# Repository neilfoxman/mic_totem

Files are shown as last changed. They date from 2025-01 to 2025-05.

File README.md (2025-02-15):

# File Structure Tour

TBD

# Firmware

## State Machine

The program is responsible for both filtering microphone samples and updating LEDs based on the filtered signals. This behavior is achieved by cycling through a loop in a state machine shown below.

```mermaid
---
title: State Machine in main.c
---
stateDiagram-v2

classDef state_style text-align:left

config_mic_s : config_mic_s
config_mic_s:::state_style
[*] --> config_mic_s
config_mic_s : <b>ENTER/</b>
config_mic_s : - Disable timer, DMA, and LED Output
config_mic_s : - Update timer period
config_mic_s : - Calculate filter params
config_mic_s : - Enable DMA, ADC, and Timer

config_mic_s --> mic_s : TIM_UE
mic_s:::state_style
mic_s : mic_s
mic_s : <b>ENTER/</b>
mic_s : <b>MIC_DMA_COMPLETE/</b>
mic_s : - Called after all ADC channels sampled once.
mic_s : - Apply filters to mic signal.

mic_s --> config_led_s : num_samples_taken >= num_samples_before_LED
config_led_s : config_led_s
config_led_s:::state_style
config_led_s : <b>ENTER/</b>
config_led_s : - Disable timer, ADC, and DMA
config_led_s : - Calculate new LED Values and generate CCR values in array
config_led_s : - Update timer period
config_led_s : - Enable DMA and timer.

config_led_s --> led_s : TIM_UE
led_s : led_s
led_s:::state_style
led_s : <b>ENTER/</b>

led_s --> config_mic_s : LED_DMA_COMPLETE

```

The loops takes advantage of persistence of vision i.e. we can take a number of microphone samples then pause periodically to update LED values.  Note that the timer is used both for triggering samples of the microphone, then repurposed in output compare mode to communicate with the LEDs.

## Microphone Filtering

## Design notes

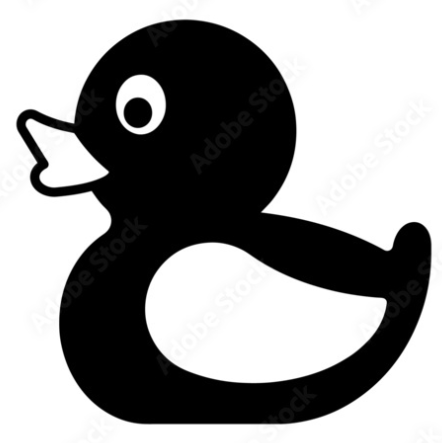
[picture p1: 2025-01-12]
Duckie.png

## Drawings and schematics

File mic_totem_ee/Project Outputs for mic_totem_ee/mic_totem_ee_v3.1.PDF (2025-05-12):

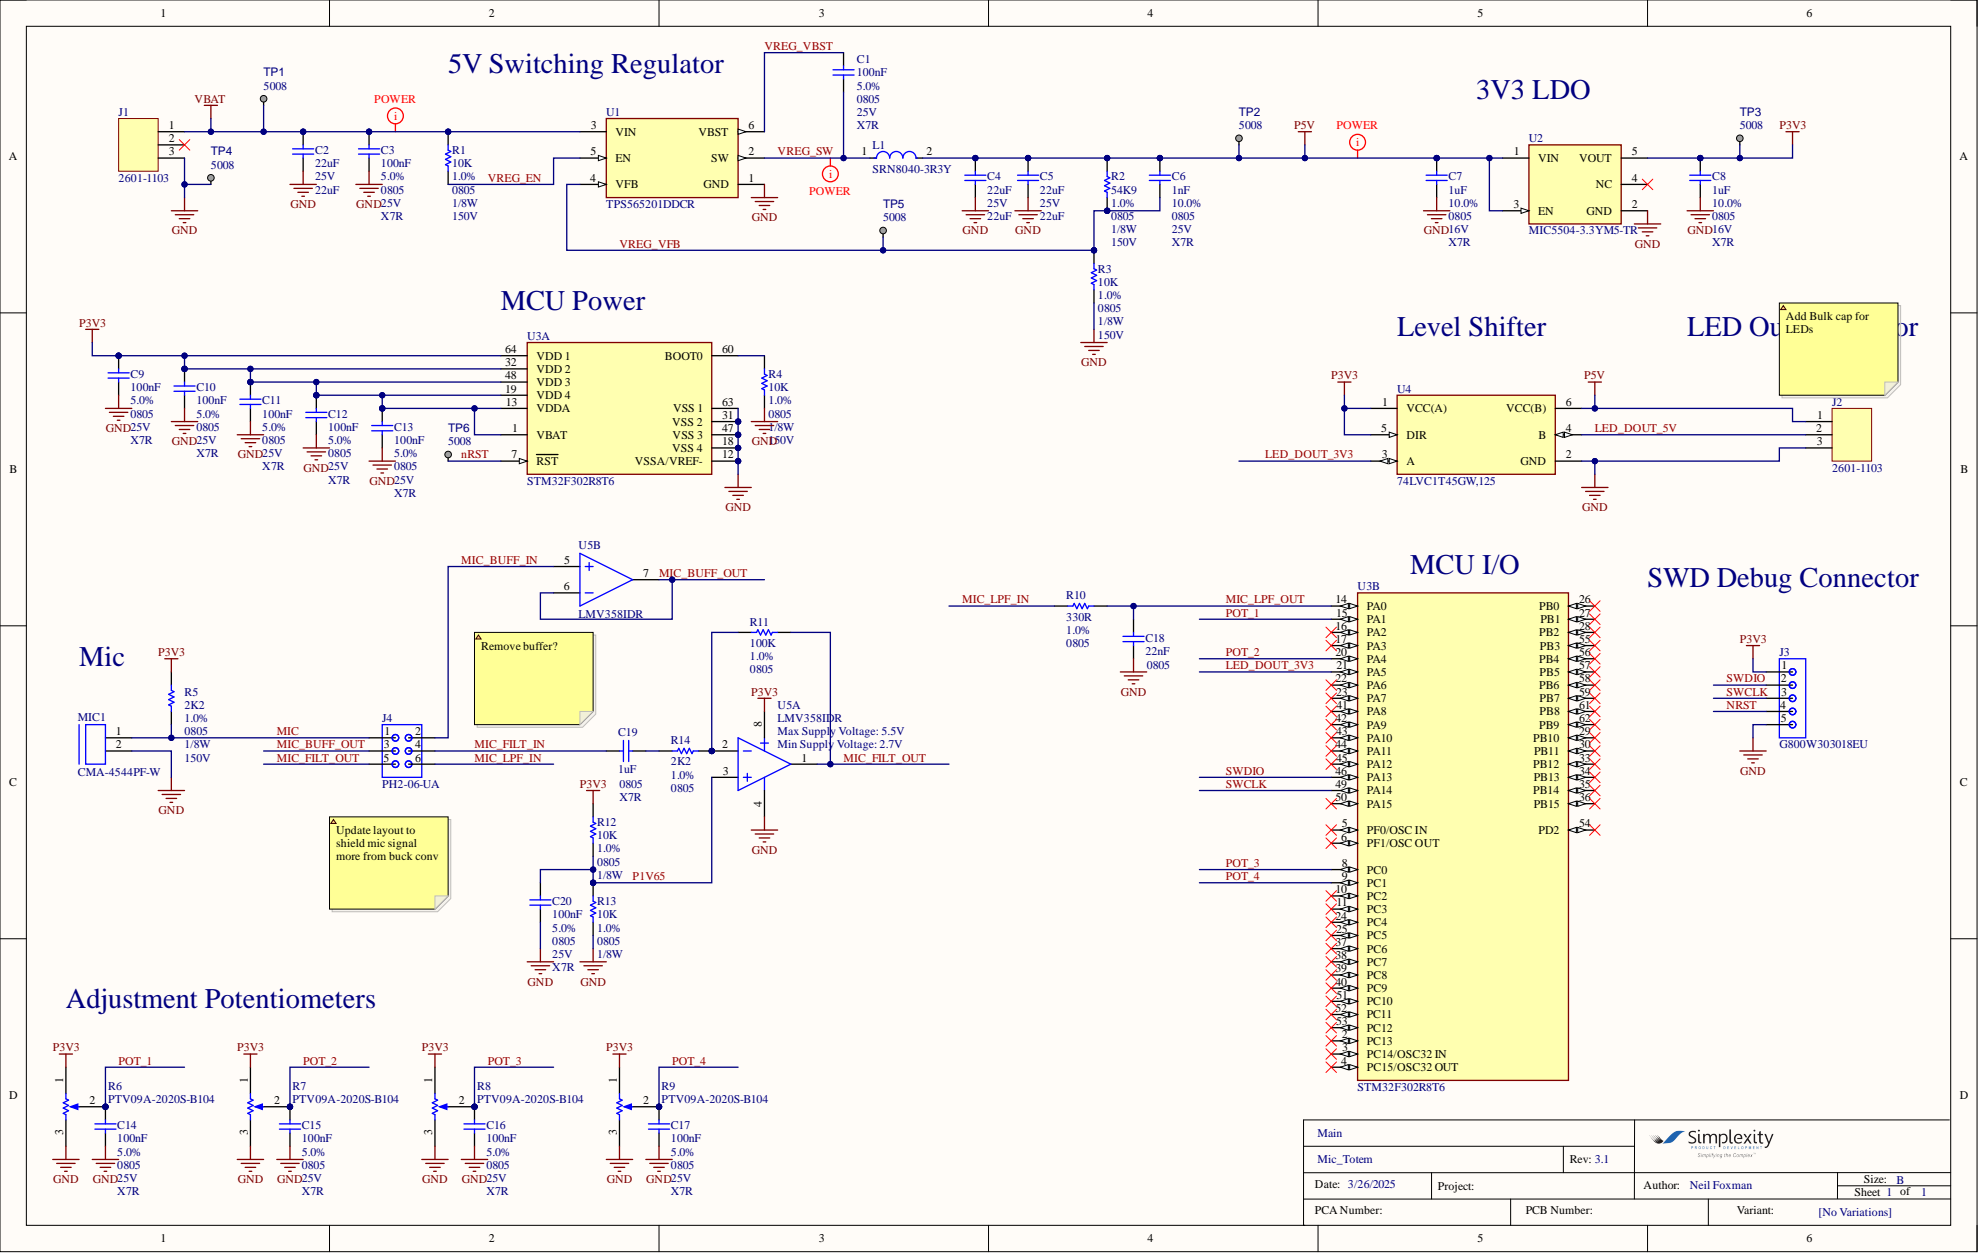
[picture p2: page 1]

Add Bulk cap for
LEDs

VDD 2 32
VDD 3 48
VDD 4 19

Update layout to
shield mic signal
more from buck conv

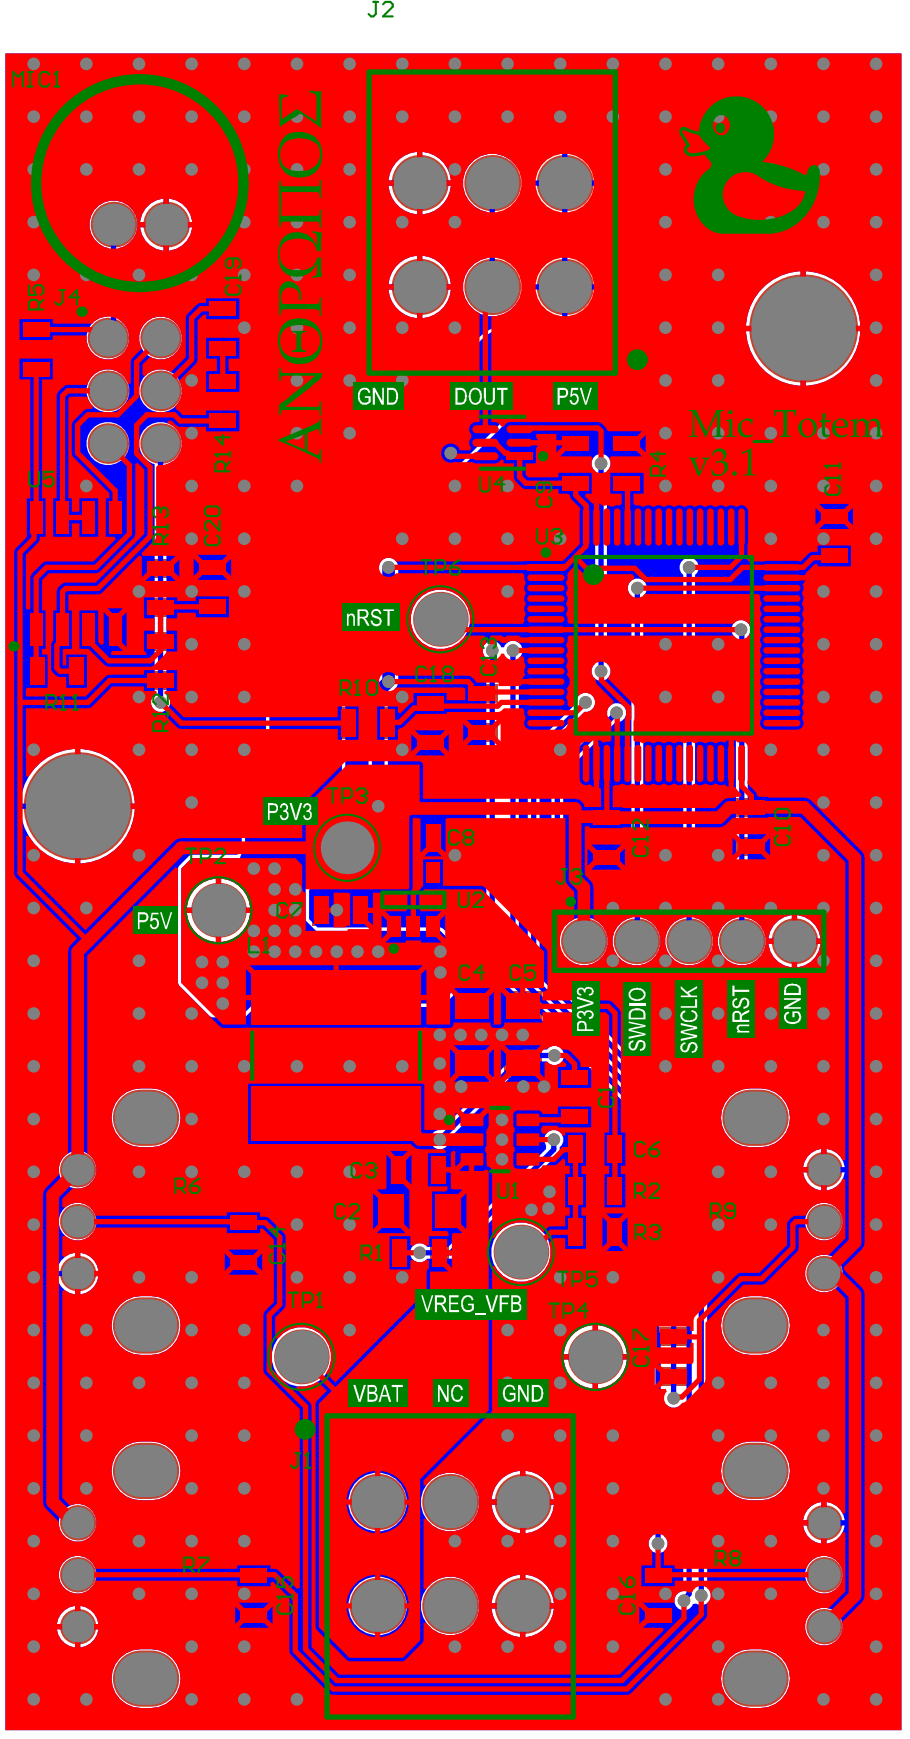
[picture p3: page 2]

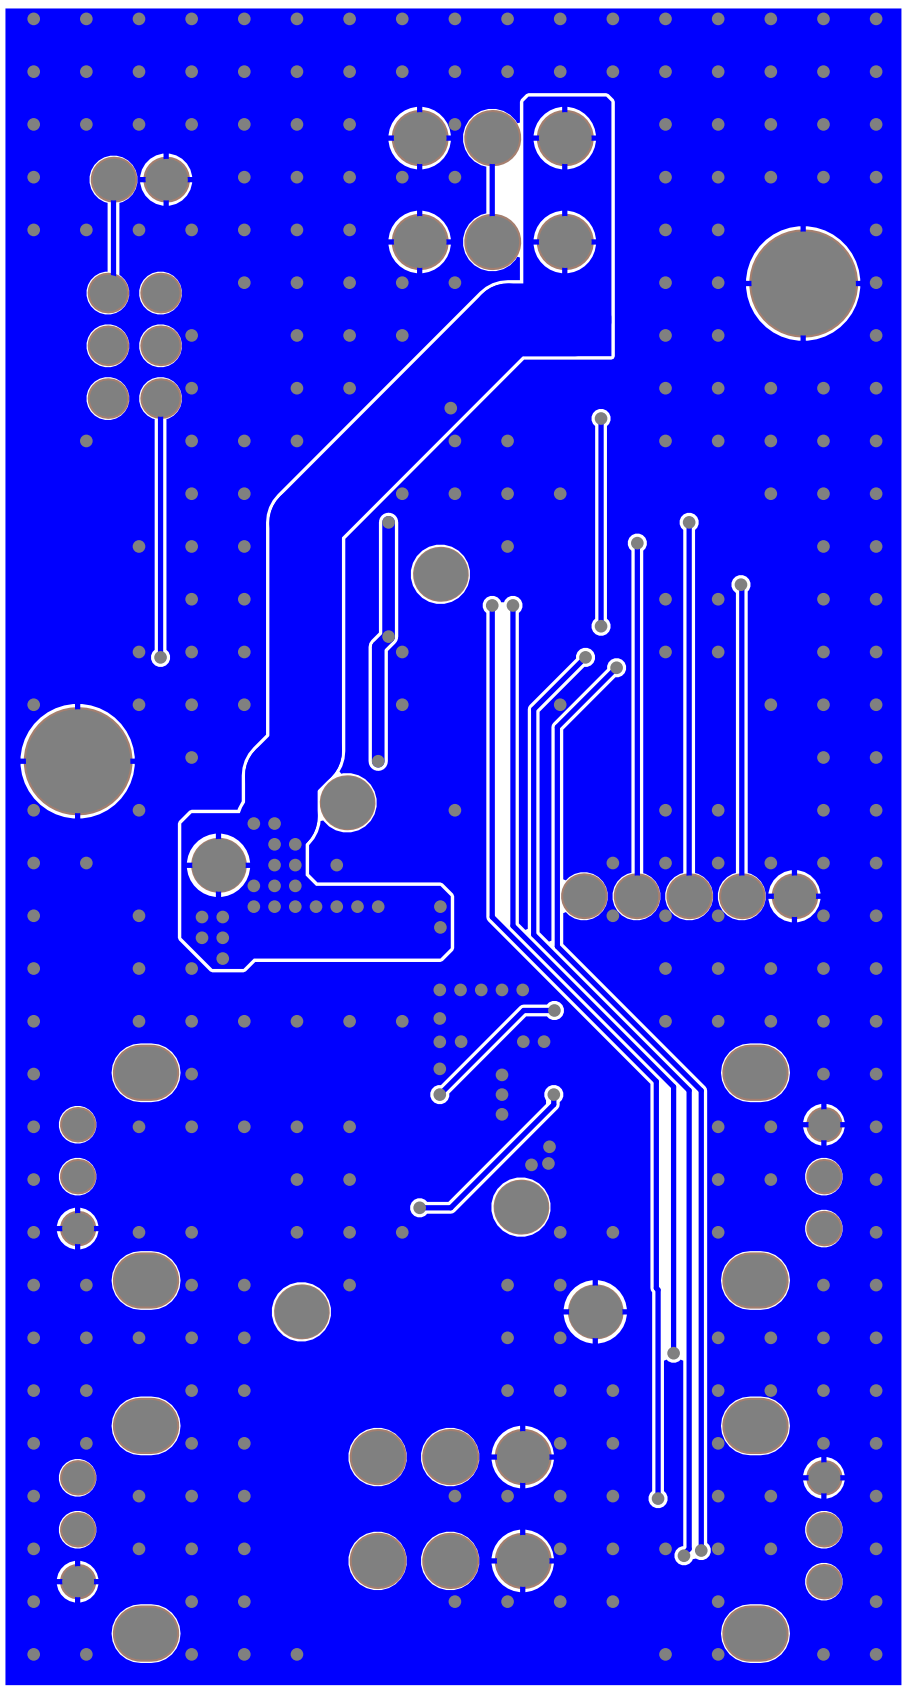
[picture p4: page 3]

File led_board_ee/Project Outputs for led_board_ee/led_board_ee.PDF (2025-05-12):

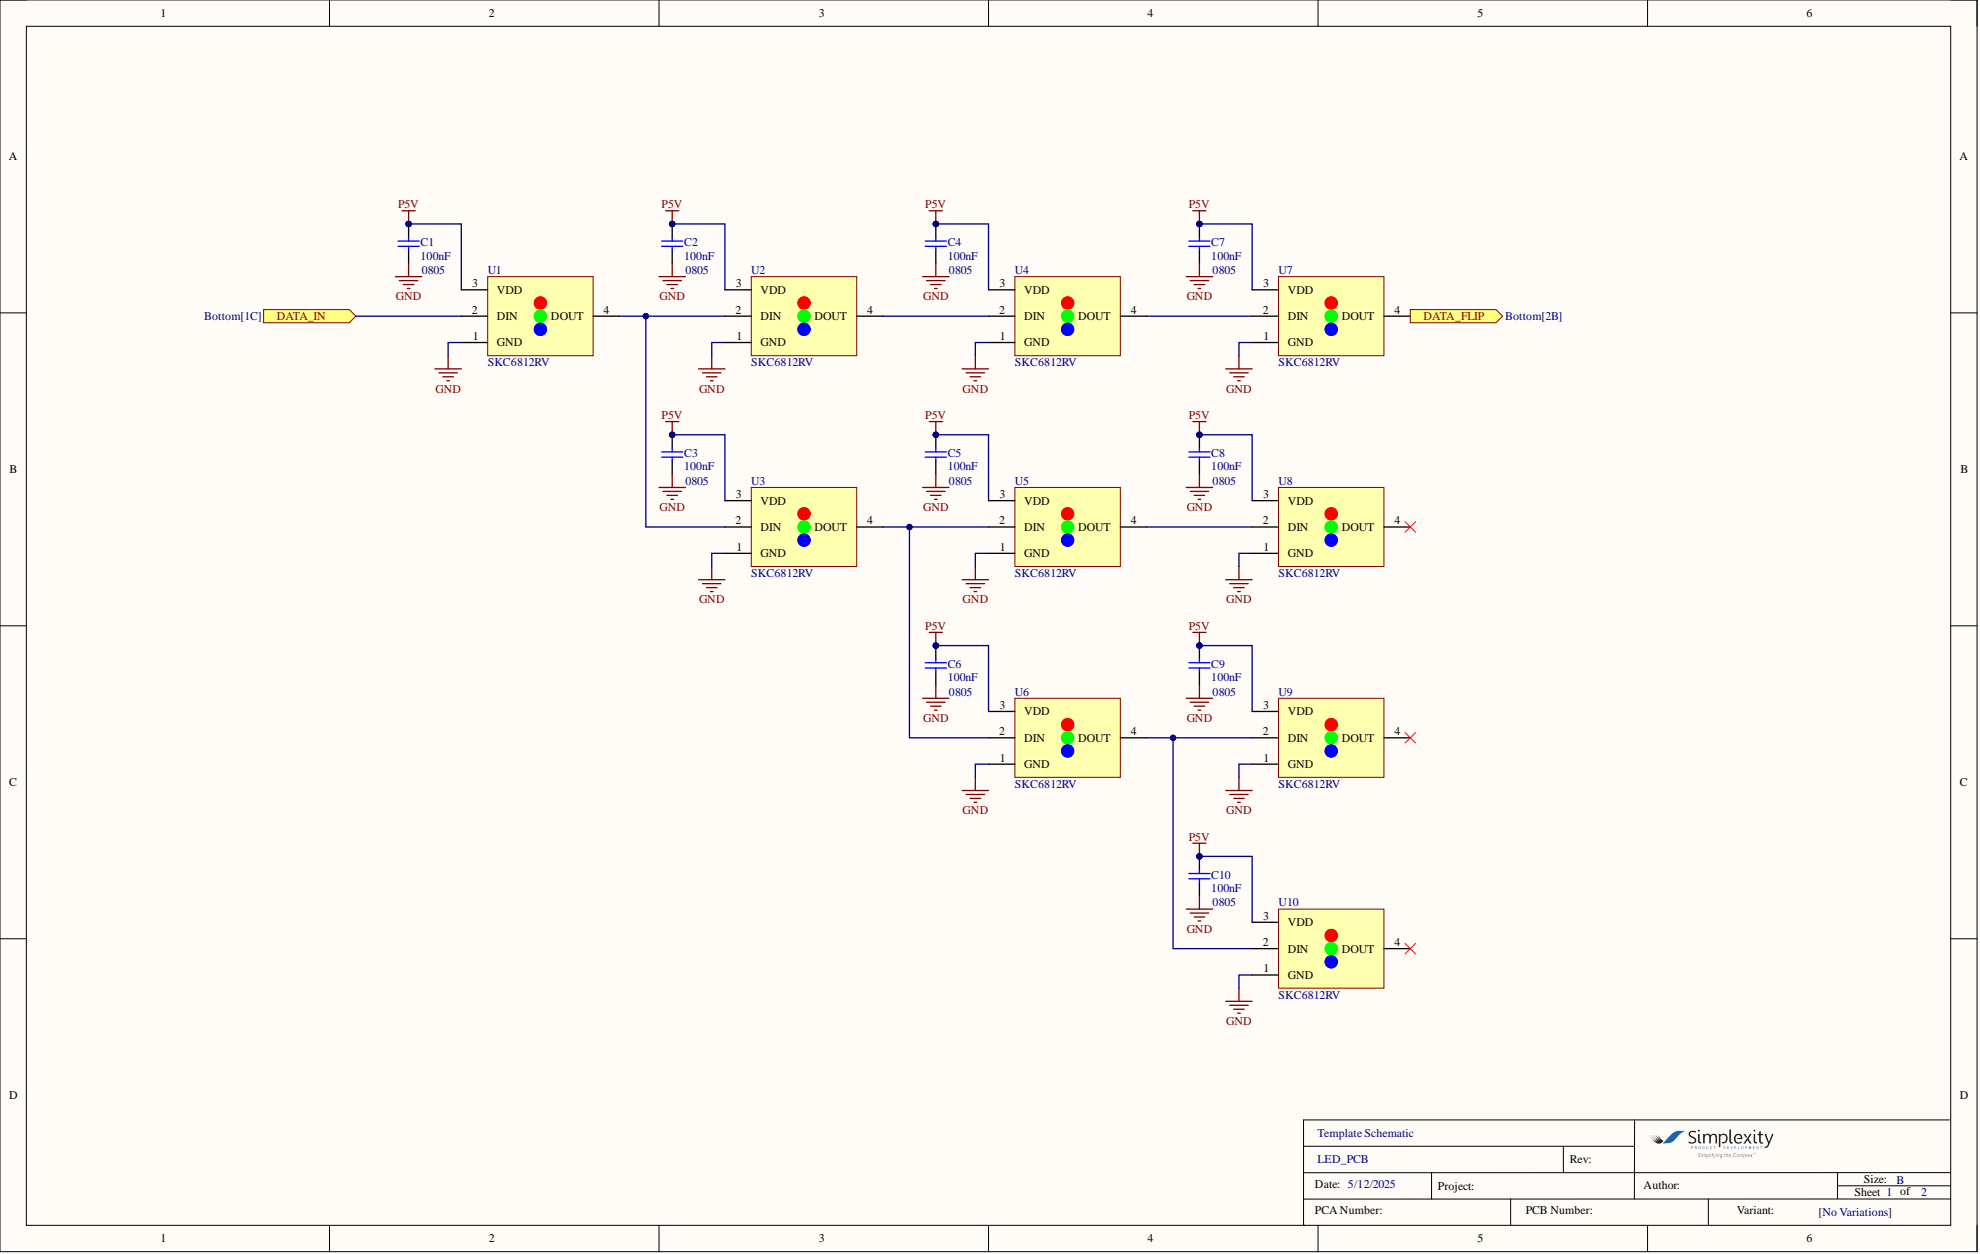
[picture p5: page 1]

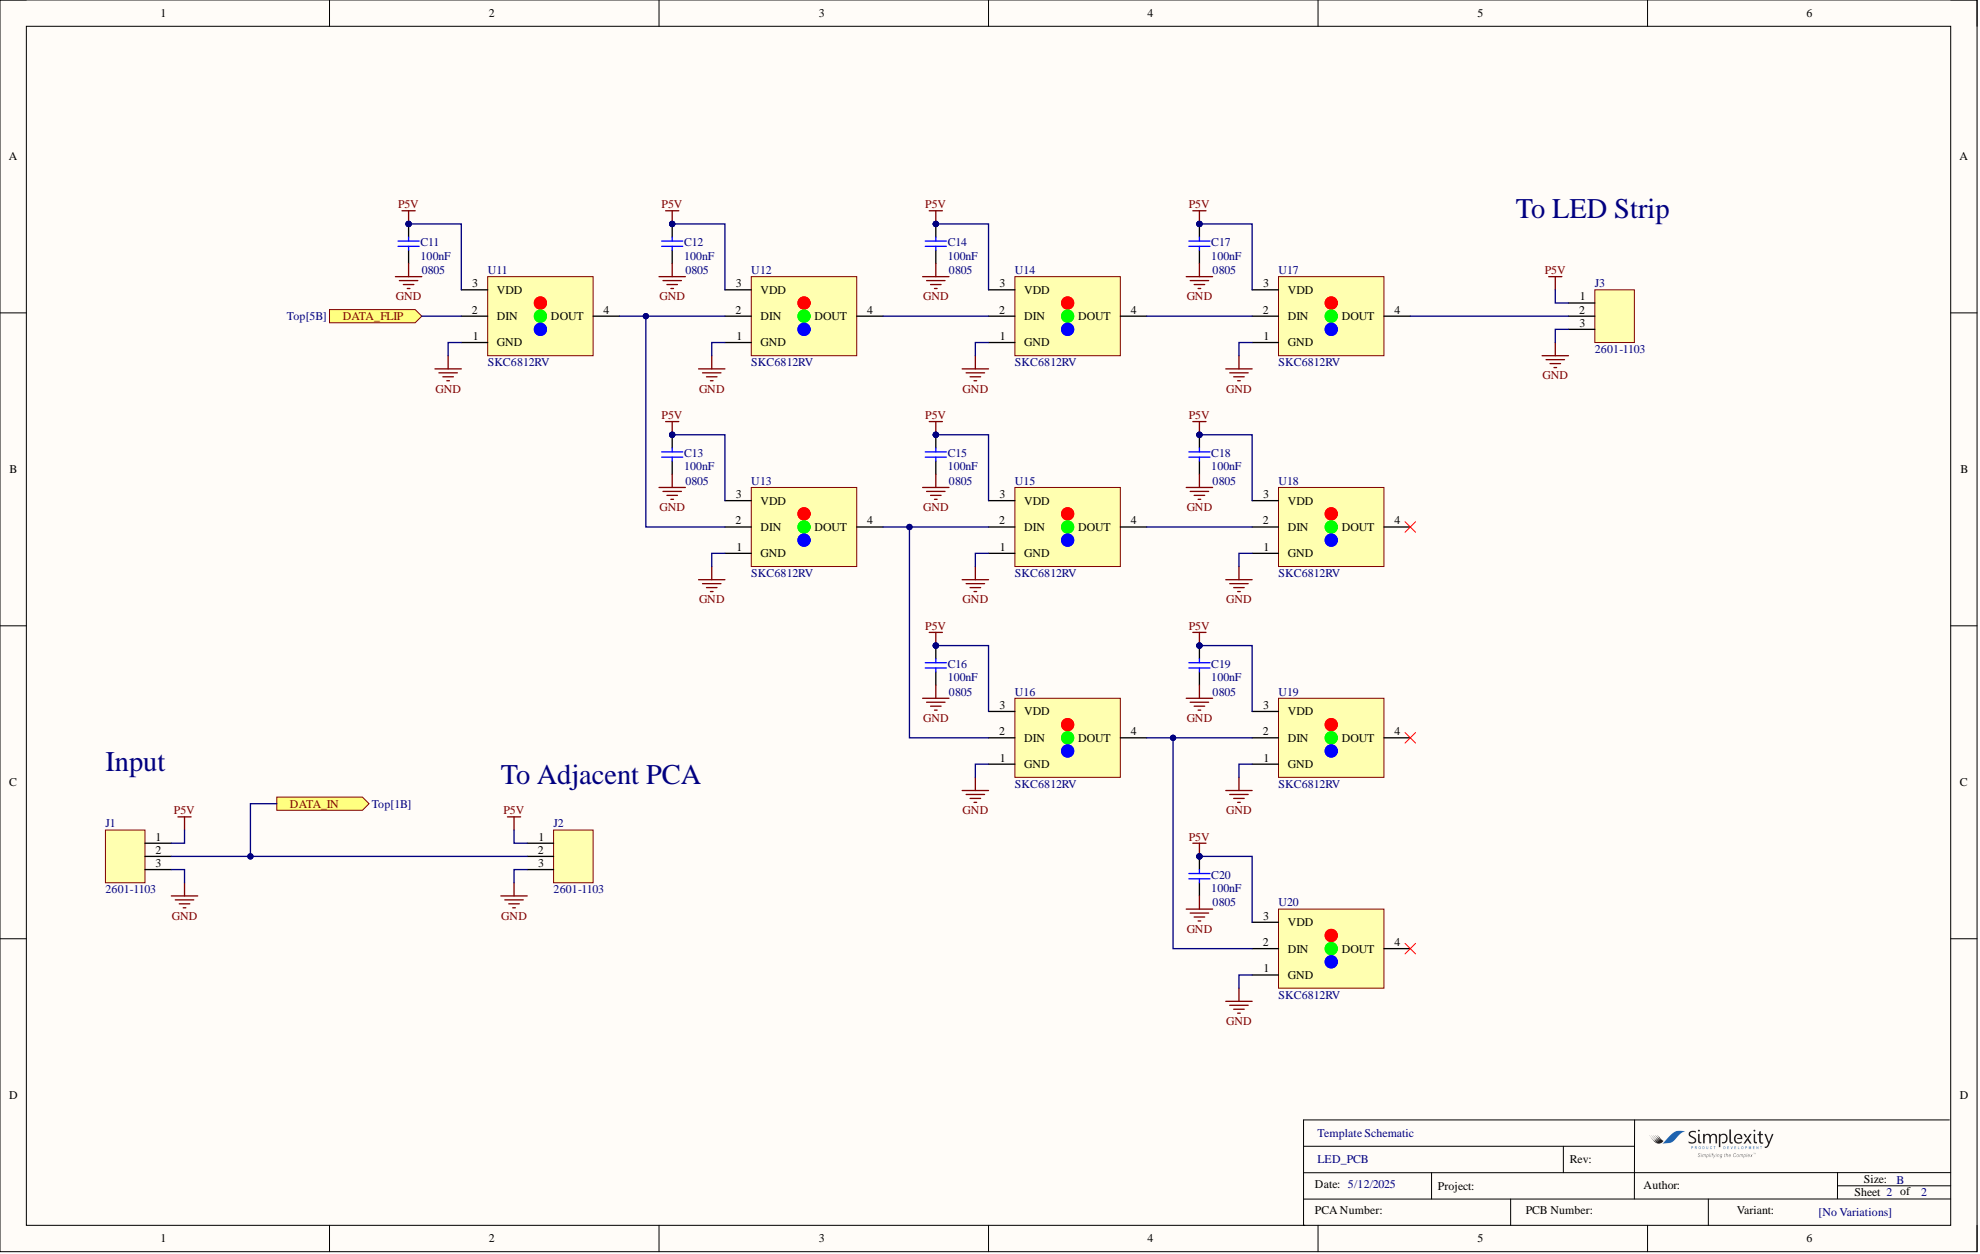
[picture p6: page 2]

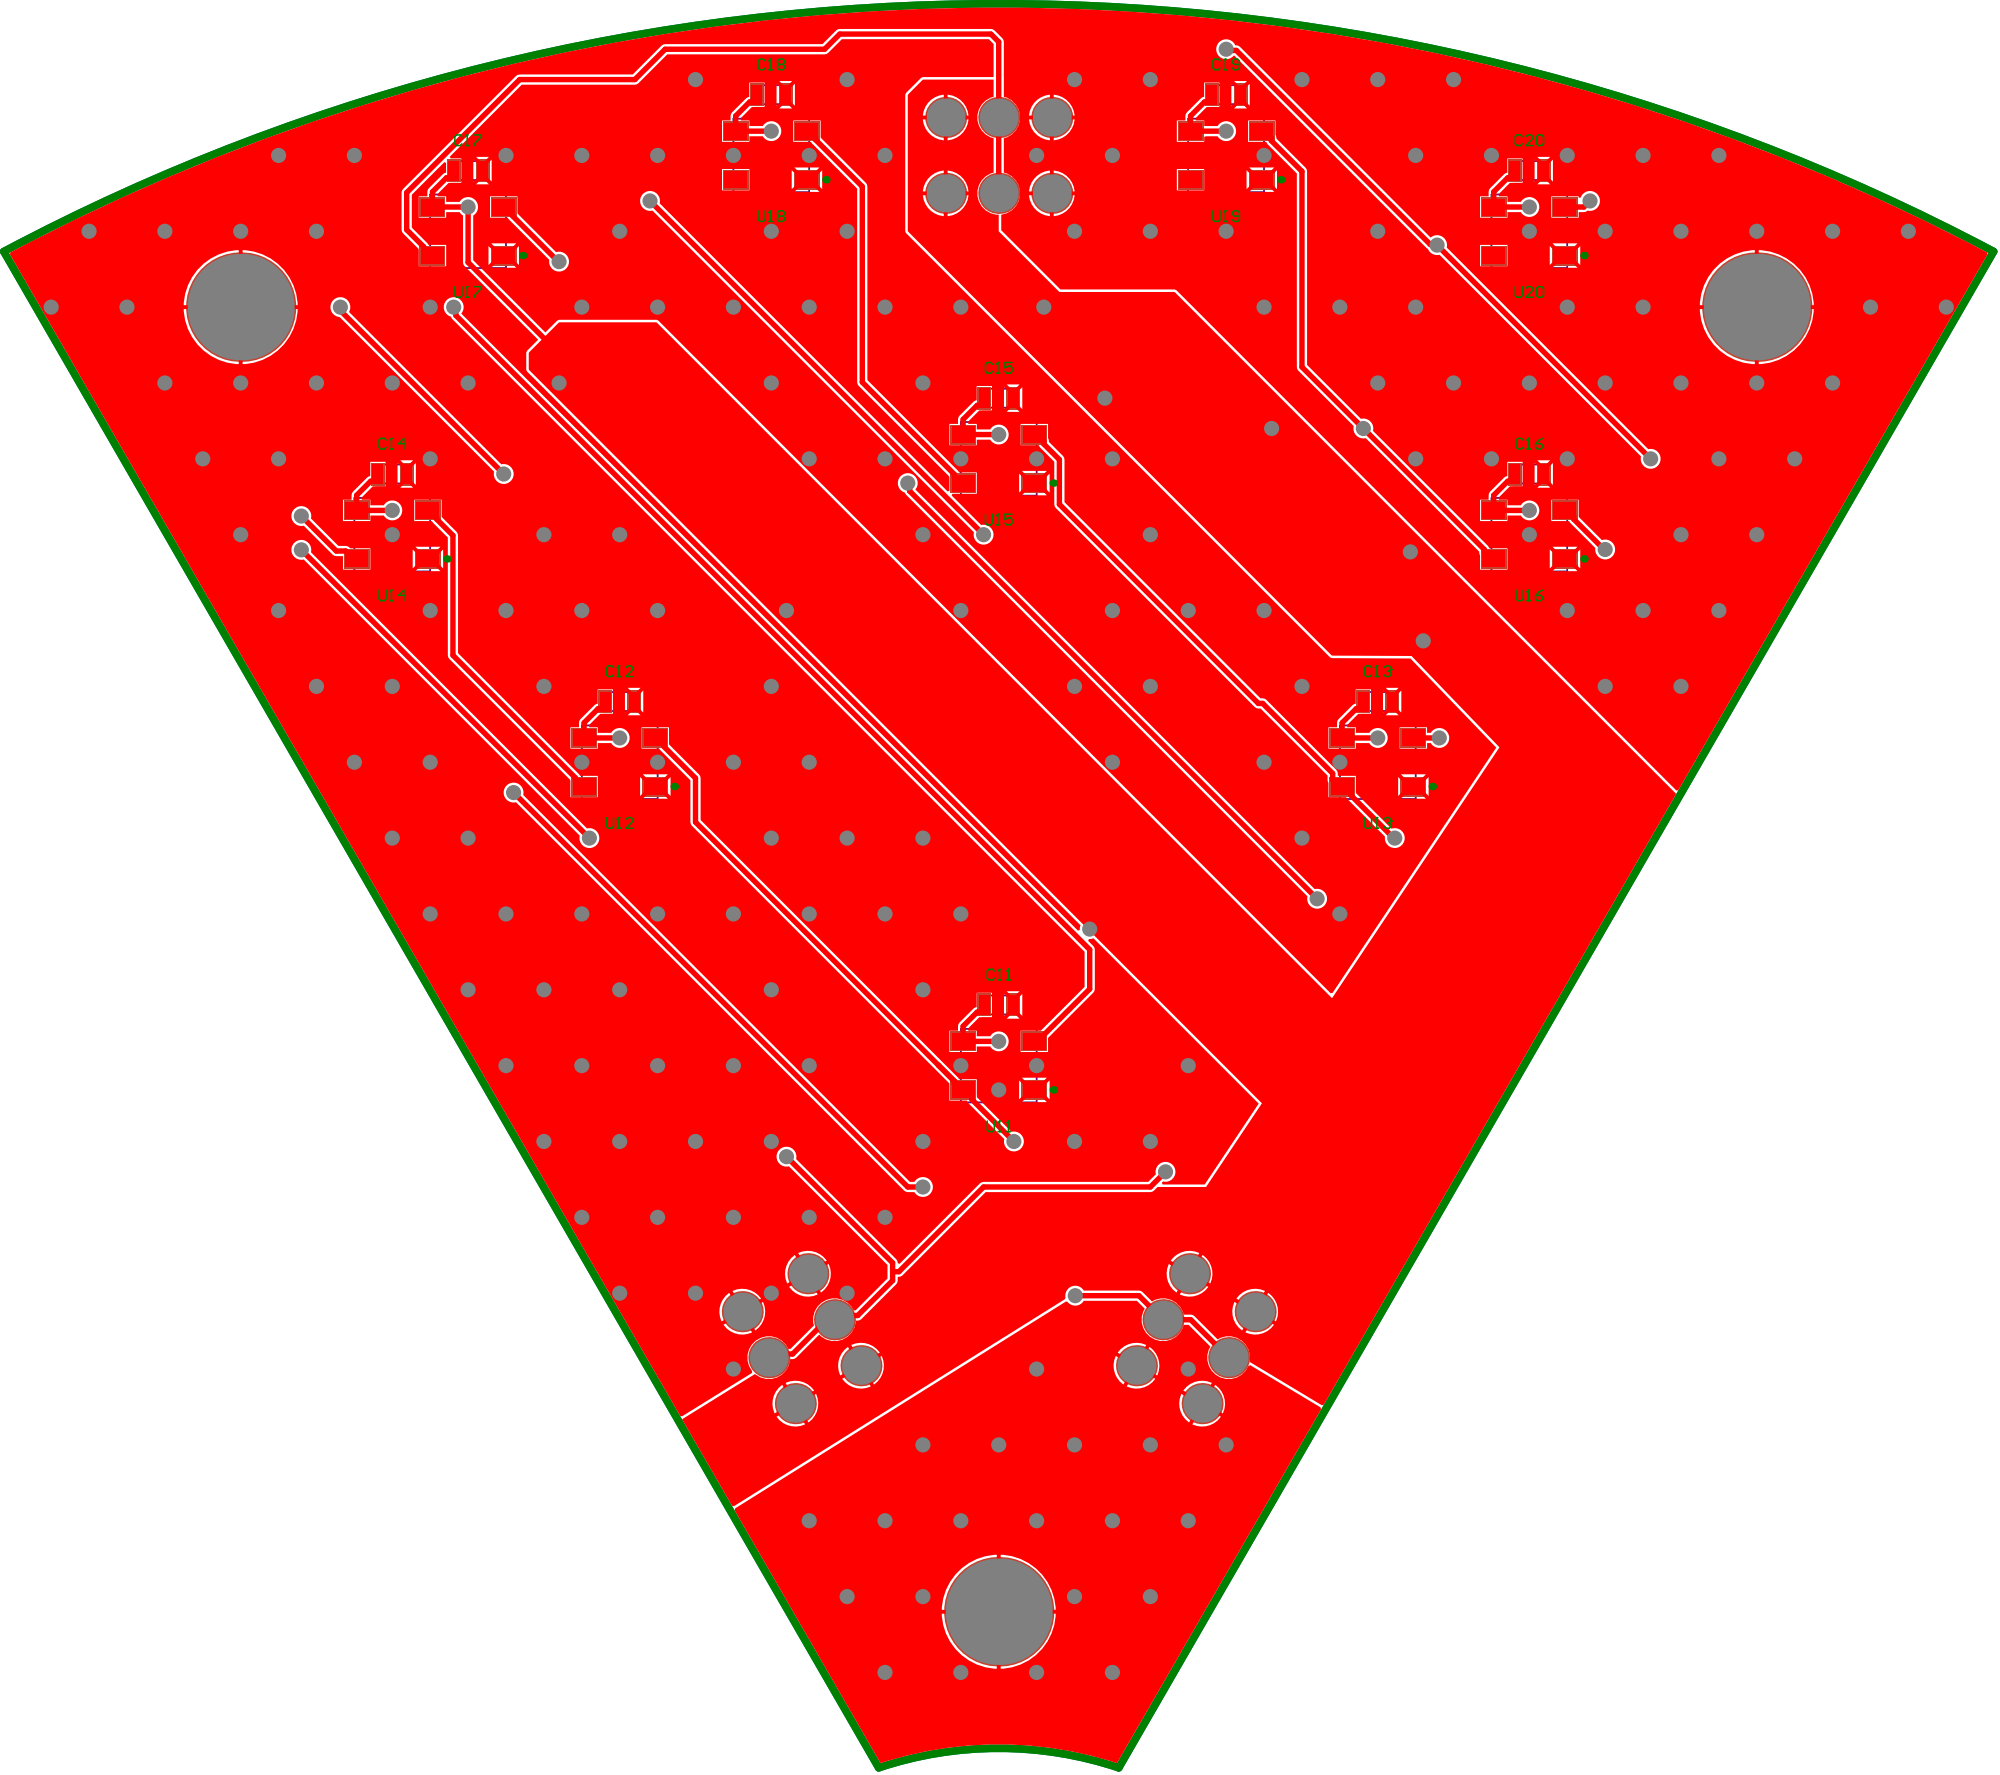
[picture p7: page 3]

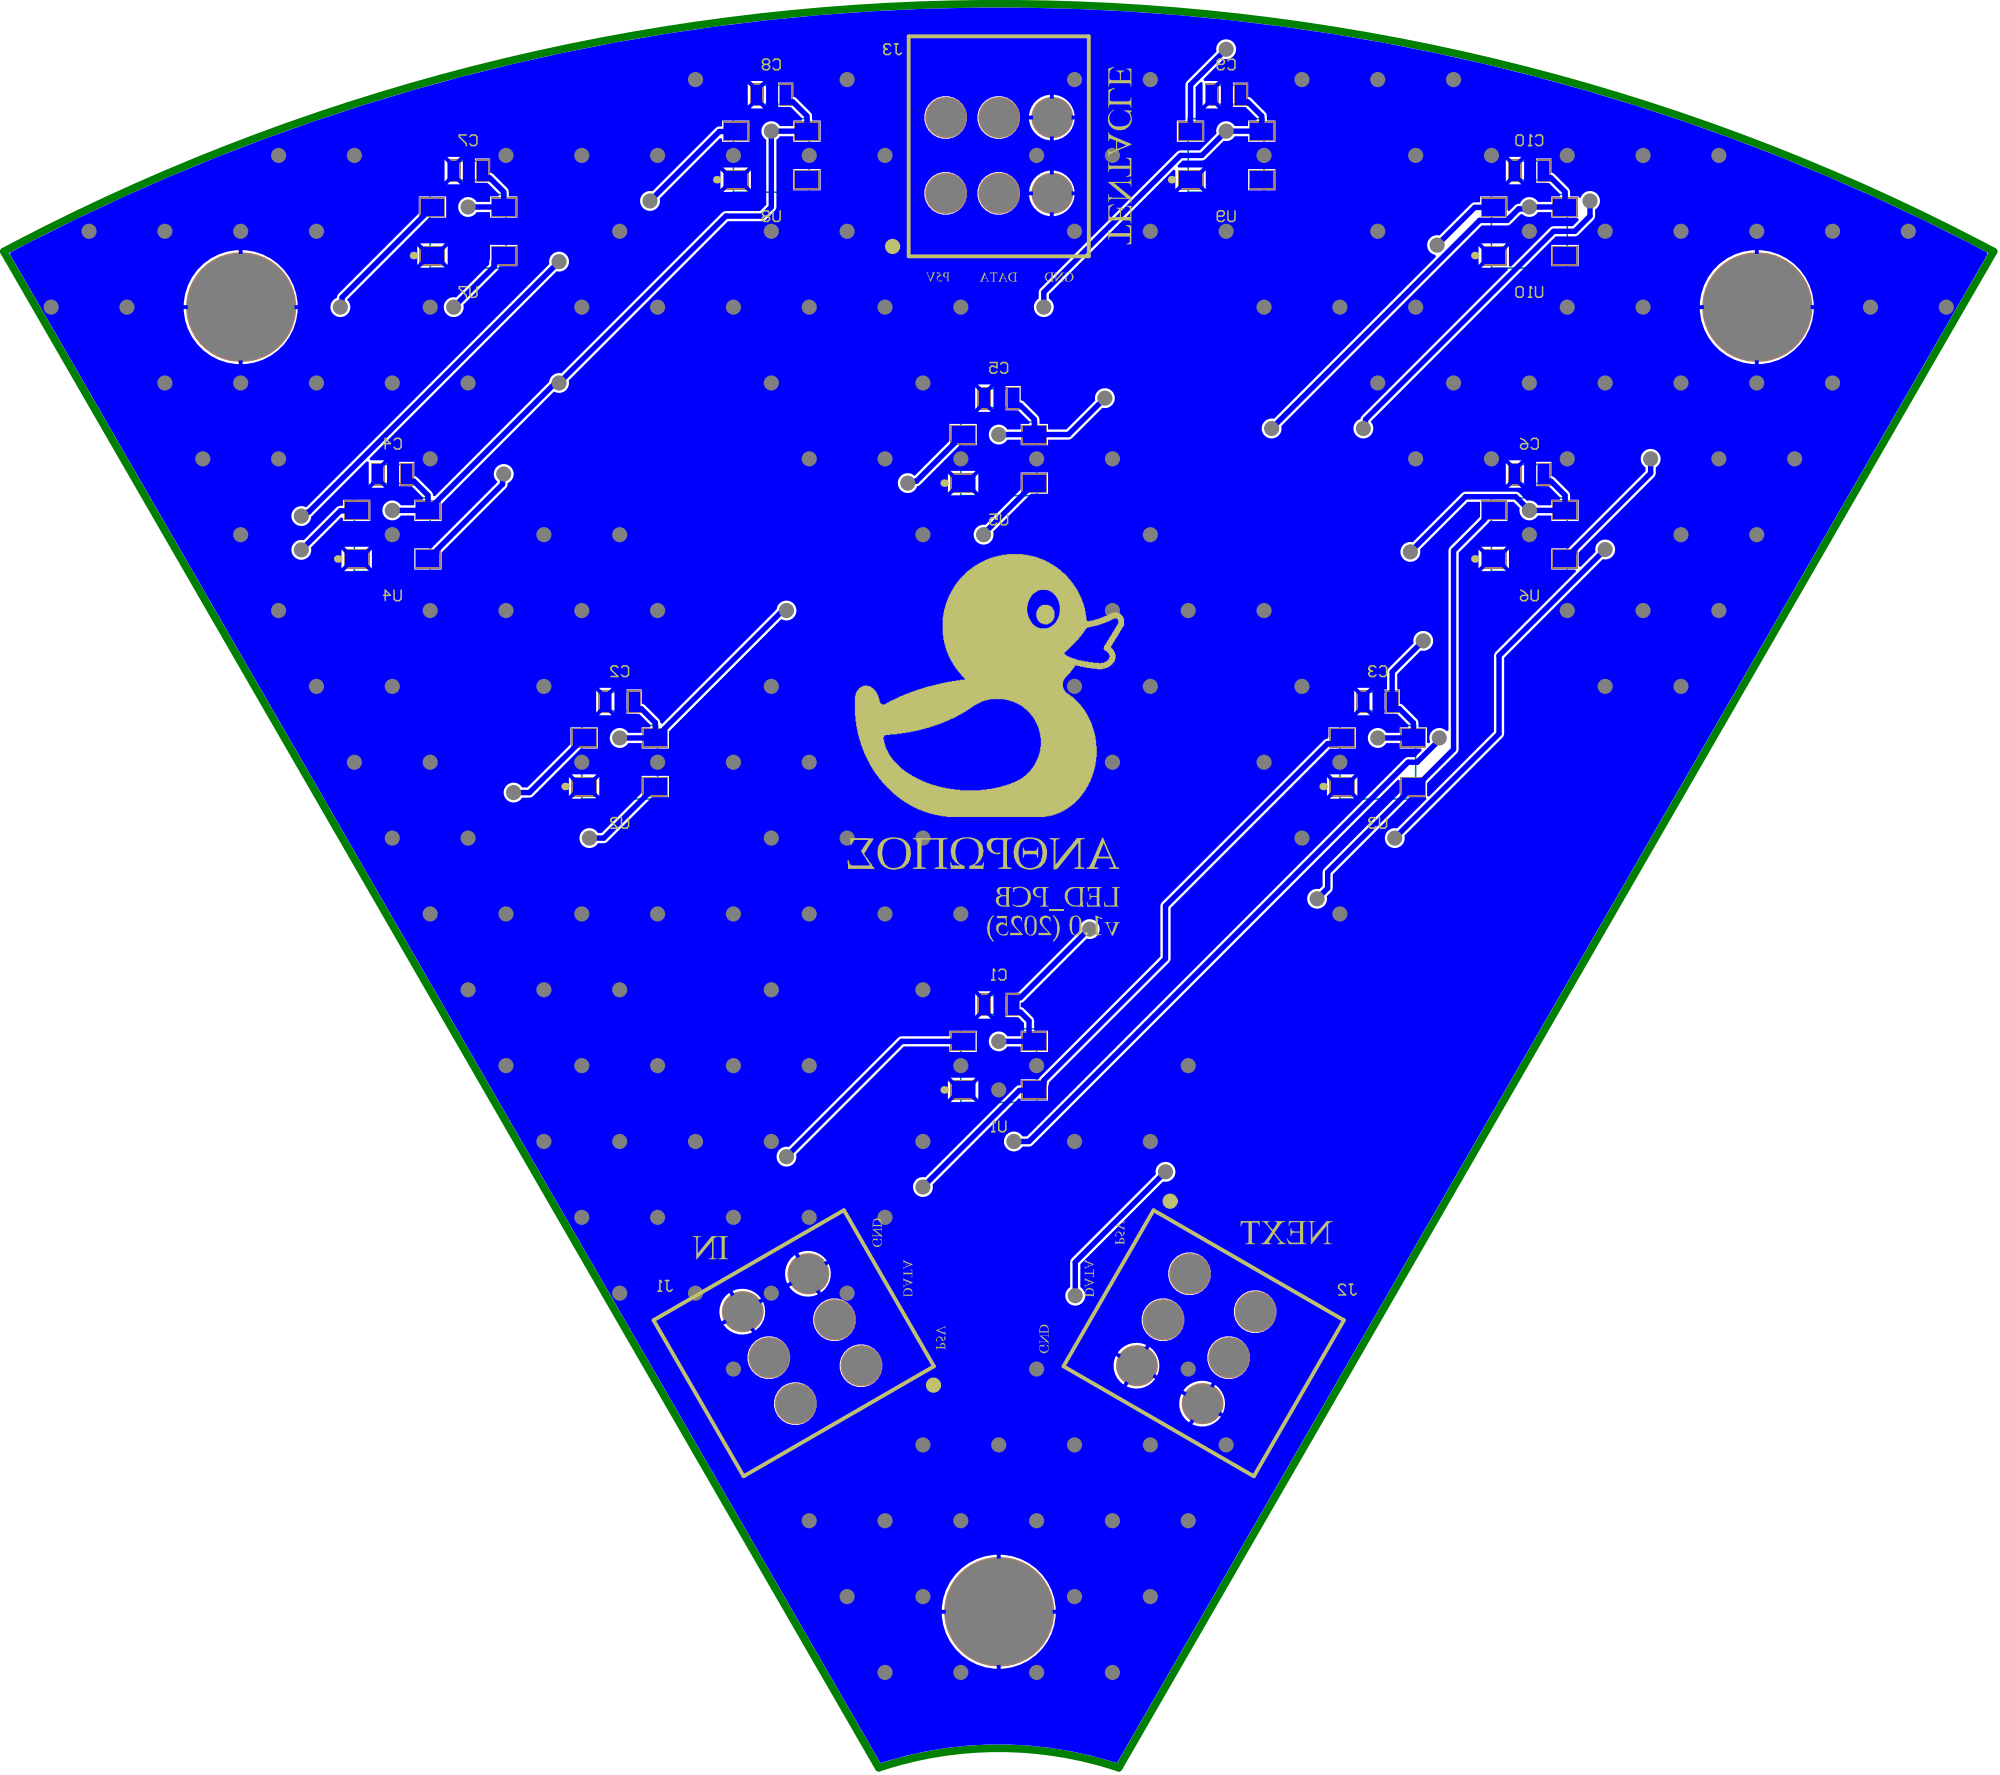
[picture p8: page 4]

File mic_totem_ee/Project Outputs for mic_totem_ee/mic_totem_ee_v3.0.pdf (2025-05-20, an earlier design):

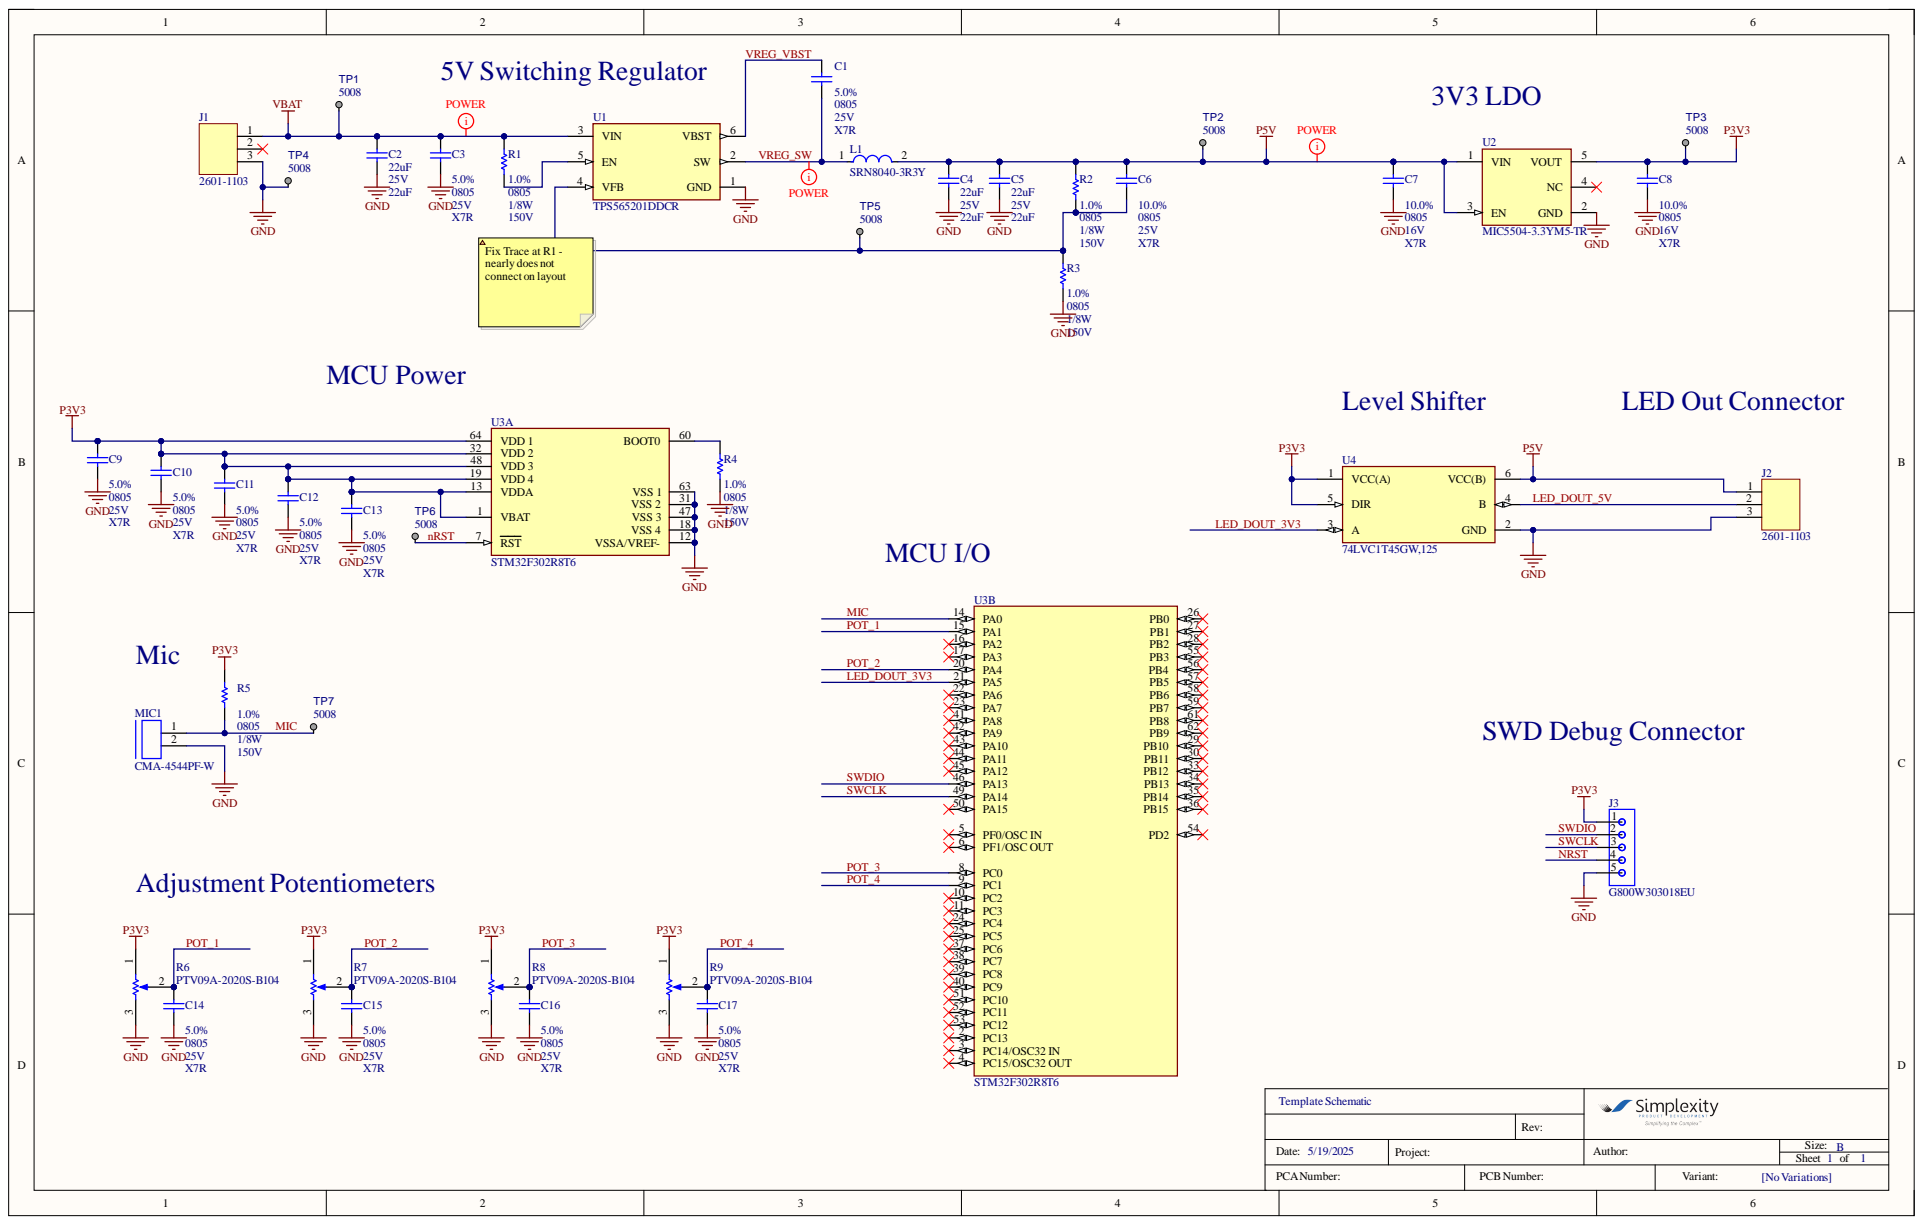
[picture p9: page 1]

VDD 2 32
VDD 3 48

VDDA 13

Template Schematic

Rev:

Project: | | Size: Date: 1 B Author: 1 5/19/2025

PCANumber: | PCBNumber: | Variant: [No Variations]

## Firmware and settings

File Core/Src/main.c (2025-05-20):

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
/* Includes ------------------------------------------------------------------*/
#include "main.h"

/* USER CODE BEGIN Includes */
#include <stdlib.h>
#include <stdio.h>
#include <math.h>
#include "cirbuf.h"
#include "sm.h"

/* USER CODE END Includes */


void SystemClock_Config(void);
static void MX_GPIO_Init(void);
static void MX_DMA_Init(void);
static void MX_TIM2_Init(void);
static void MX_ADC1_Init(void);
/* USER CODE BEGIN 0 */

const uint32_t adc1_isr_clear_mask =
	ADC_ISR_JQOVF |
	ADC_ISR_AWD3 |
	ADC_ISR_AWD2 |
	ADC_ISR_AWD1 |
	ADC_ISR_JEOS |
	ADC_ISR_JEOC |
	ADC_ISR_OVR |
	ADC_ISR_EOS |
	ADC_ISR_EOC;

// External variable used for tracking how long certain processes take to complete
uint32_t proc_time;

// OVR Event tracking variable
uint32_t ovr_cnt = 0;

// FSM State Prototypes
void config_mic_s(Event evt);
void mic_s(Event evt);
void config_led_s(Event evt);
void led_s(Event evt);


// Declare ADC read variables
uint16_t adc_reads[5];
#define ADC_RANK_MIC 0
#define ADC_RANK_INTENSITY_SENSITIVITY 1
#define ADC_RANK_INTENSITY_GAIN 2
#define ADC_RANK_TRANSIENT_SENSITIVITY 4
#define ADC_RANK_TRANSIENT_GAIN 3

// Common variables for all DSP circular buffers.
#define MIC_CIRBUF_LEN 255
uint16_t mic_cirbuf_idx = 0; // Index used for tracking current location in circular buffers
uint16_t mic_cirbuf_idx_minus_1 = MIC_CIRBUF_LEN-1;

// Mic signal
float f_s;
int32_t cirbuf_mic[MIC_CIRBUF_LEN];

// Incoming signal HPF
int32_t cirbuf_hpf[MIC_CIRBUF_LEN];
int32_t tau_over_T_hpf;
int32_t gain_hpf;

// Envelope Signal
int32_t cirbuf_env[MIC_CIRBUF_LEN];
int32_t gain_env;
int32_t cirbuf_env_scaled[MIC_CIRBUF_LEN];

// Transient Sensitivity configuration variables
int32_t transient_sensitivity_shifts;
int32_t transient_thresh;

// HPF for beat detect
int32_t cirbuf_hpf_beat[MIC_CIRBUF_LEN];
int32_t tau_over_T_hpf_beat;
int32_t gain_hpf_beat;
int32_t transient_present = 0; // This variable gets reset every tim the LEDs are updated

// Number of mic samples before switch states to set LEDs
uint32_t num_samples_before_LED = 1000;
uint32_t num_samples_taken = 0;

void config_mic_s(Event evt){
	switch(evt){
			case ENTER:
				// Disable led_s configuration ~~~~~~~~~~~~~~~~~~~~~~~~~~
//				proc_time = TIM2->CNT;
				// Disable counter temporarily to configure peripherals
				LL_TIM_DisableCounter(TIM2);

				// Disable DMA requests triggering on update events
				LL_TIM_DisableDMAReq_UPDATE(TIM2);

				// Disable DMA
				LL_DMA_DisableChannel(DMA1, LL_DMA_CHANNEL_1);
				LL_DMA_DisableChannel(DMA1, LL_DMA_CHANNEL_2);
				SET_BIT(DMA1->IFCR, DMA_IFCR_CGIF1 | DMA_IFCR_CGIF2);

				// Force reset counter using update event
				LL_TIM_GenerateEvent_UPDATE(TIM2);

				// Set CCR to 0 so outputting a low (reset) value
				LL_TIM_OC_SetCompareCH1(TIM2, 0);

				// Configure for mic_s ~~~~~~~~~~~~~~~~~~~~~~~~~~
				// Define Sample Frequency
				const uint32_t mic_arr = 950;
				LL_TIM_SetAutoReload(TIM2, mic_arr); // Set timer ARR such that DSP can complete in one cycle
				float T_s = (float)mic_arr / 64E6;
				f_s = 1.0 / T_s;

				// Incoming signal HPF
				const float f_n_hpf = 20;
				tau_over_T_hpf = CalcTauOverTFromFloat(f_n_hpf, f_s);
				gain_hpf = 1;

				// Envelope signal
				gain_env = 100;

				// HPF for beat detect
				const float f_n_hpf_beat = 500;
				tau_over_T_hpf_beat = CalcTauOverTFromFloat(f_n_hpf_beat, f_s);
				gain_hpf_beat = 255;

				// Calculate Transient Threshold based on ADC read and intensity (threshold is scaled intensity value)
				transient_sensitivity_shifts = ( adc_reads[ADC_RANK_TRANSIENT_SENSITIVITY] * 30) / 4095;
				transient_thresh = 1 << transient_sensitivity_shifts;

				// Reset sample tracker
				num_samples_taken = 0;

				// Clear any pending status registers
				CLEAR_REG(TIM2->SR);
				SET_BIT(DMA1->IFCR, DMA_IFCR_CGIF1 | DMA_IFCR_CGIF2);

				// Reset DMA counter
				LL_DMA_SetDataLength(DMA1, LL_DMA_CHANNEL_1, 5);
				while(LL_DMA_GetDataLength(DMA1, LL_DMA_CHANNEL_1) != 5){}

				// Enable DMA
				LL_DMA_EnableChannel(DMA1, LL_DMA_CHANNEL_1);

				// Enable ADC
				LL_ADC_Enable(ADC1);

				// Start ADC triggering on TRGO events
				LL_ADC_REG_StartConversion(ADC1);

				// Enable counter. Transition to next state occurs on the next update event
				LL_TIM_EnableCounter(TIM2);
				break;
			case TIM_UE:
				// Transition to next state
				transition(mic_s);
			default:
				break;
		}
}

void mic_s(Event evt){
	switch(evt){
		case ENTER:
			break;
		case ADC_OVR:
			ovr_cnt++; // Increment counter (for debugging)
			break;
		case MIC_DMA_COMPLETE:
			// Increment sample counter
			num_samples_taken++;

			// Increment circular buffer index to store next read from ADC
			mic_cirbuf_idx_minus_1 = mic_cirbuf_idx;
			mic_cirbuf_idx = (mic_cirbuf_idx + 1) % MIC_CIRBUF_LEN;

			// Save new mic read every sample
			cirbuf_mic[mic_cirbuf_idx] = adc_reads[ADC_RANK_MIC];

			// Apply HPF to incoming signal
			cirbuf_hpf[mic_cirbuf_idx] = ApplyFirstDifferenceHPF(
				cirbuf_hpf[mic_cirbuf_idx_minus_1],
				cirbuf_mic[mic_cirbuf_idx],
				cirbuf_mic[mic_cirbuf_idx_minus_1],
				tau_over_T_hpf,
				gain_hpf
			);

			// Envelope Signal to be used for intensity (downsampled and LPF version of envelope)
			cirbuf_env[mic_cirbuf_idx] = ApplyFirstDifferenceEnvelopeLinear(
				cirbuf_env[mic_cirbuf_idx_minus_1],
				abs(cirbuf_hpf[mic_cirbuf_idx]),
				gain_env
			);
			cirbuf_env_scaled[mic_cirbuf_idx] = cirbuf_env[mic_cirbuf_idx] / gain_env;

			// Beat Detect HPF
			cirbuf_hpf_beat[mic_cirbuf_idx] = ApplyFirstDifferenceHPF(
				cirbuf_hpf_beat[mic_cirbuf_idx_minus_1],
				cirbuf_mic[mic_cirbuf_idx],
				cirbuf_mic[mic_cirbuf_idx_minus_1],
				tau_over_T_hpf_beat,
				gain_hpf_beat
			);

			// Beat detect threshold
			if (abs(cirbuf_hpf_beat[mic_cirbuf_idx]) > transient_thresh)
			{
				transient_present++;
			}

			if(num_samples_taken >= num_samples_before_LED){
				transition(config_led_s);
			}

			// Capture time at end of processing for setting good sample frequency
			proc_time = TIM2->CNT;
			break;
		default:
			break;
	}
}

// LED output variables
#define NUM_LEDS 68
#define NUM_LED_CHANNELS 3
uint8_t led_vals[NUM_LEDS][NUM_LED_CHANNELS];

// Variables used when converting from bits to Timer CCR durations
#define NUM_CCRS (NUM_LEDS * NUM_LED_CHANNELS * 8)
uint32_t ccr_zero = 19;
uint32_t ccr_one = 45;
uint32_t ccr_sequence[NUM_CCRS];

uint32_t led_arr = 79;

uint32_t refresh_cntr = 0;

// Each color channel intensity component oscillates at different frequencies and
// is dependent on measured intensity. Periods are measured in number of LED refresh cycles.
const float led_chan_periods[NUM_LED_CHANNELS] = {60, 105, 135};
uint32_t led_chan_periods_lcm;

// Circular buffer variables for LED (updated once every time we switch to led_s
#define LED_CIRBUF_LEN 127
uint32_t led_cirbuf_idx = 0;

// Intensity signal (downsampled envelope with LPF)
int32_t cirbuf_env_downsample[LED_CIRBUF_LEN];
int32_t intensity_lpf_accum = 0; // Accumulator used when applying LPF to store sum between samples
int32_t cirbuf_intensity[LED_CIRBUF_LEN];
uint32_t intensity;
float intensity_gain;
float intensity_scaled;
uint32_t intensity_shifts;
float led_intensity_component[NUM_LED_CHANNELS];


// Declare LED variables external from state machine for easier tracking/debugging
float transient_gain;
uint8_t transient_locations[NUM_LEDS];
float led_transient_component[NUM_LEDS];
float i_and_t;

void config_led_s(Event evt){
    switch(evt){
		case ENTER:
			// Disable mic_s configuration ~~~~~~~~~~~~~~~~~~~~~~~~~~
			// Disable counter temporarily to configure peripherals
			LL_TIM_DisableCounter(TIM2);

			// Stop ADC conversions (and therefore no DMA requests will be generated)
			LL_ADC_REG_StopConversion(ADC1);
			while (READ_BIT(ADC1->CR, ADC_CR_ADSTART) > 0){}

			// Disable ADC
//			LL_ADC_Disable(ADC1);
//			while (READ_BIT(ADC1->CR, ADC_CR_ADEN) > 0){}

			// Disable DMA and clear flags
			LL_DMA_DisableChannel(DMA1, LL_DMA_CHANNEL_1);
			LL_DMA_DisableChannel(DMA1, LL_DMA_CHANNEL_2);
			SET_BIT(DMA1->IFCR, DMA_IFCR_CGIF1 | DMA_IFCR_CGIF2);

			// Force reset counter using update event
			LL_TIM_GenerateEvent_UPDATE(TIM2);

			// Configure for led_s ~~~~~~~~~~~~~~~~~~~~~~~~~~
			// Update refresh counter, rollover on LCM of periods
			refresh_cntr = (refresh_cntr + 1) % led_chan_periods_lcm;

			// Update LED circular buffer index
			led_cirbuf_idx = (led_cirbuf_idx + 1) % LED_CIRBUF_LEN;

			const float led_component_max = 127.0;

			// Calculate intensity component of LEDs using LPF on down-sampled envelope signal
			cirbuf_env_downsample[led_cirbuf_idx] = cirbuf_env_scaled[mic_cirbuf_idx]; // Down-sample: assign last env value to intensity signal
			const uint32_t filt_len = LED_CIRBUF_LEN-1; // LED_CIRBUF_LEN-1 is longest filter length possible without accruing errors
			cirbuf_intensity[led_cirbuf_idx] = ApplyFIRLPF(
				cirbuf_env_downsample,
				led_cirbuf_idx,
				filt_len,
				LED_CIRBUF_LEN,
				&intensity_lpf_accum
			);
			intensity_shifts = (adc_reads[ADC_RANK_INTENSITY_GAIN] * 32) / 4095;
			intensity = cirbuf_intensity[led_cirbuf_idx] >> intensity_shifts;
			for (uint8_t chan_idx = 0; chan_idx < NUM_LED_CHANNELS; chan_idx++){
				led_intensity_component[chan_idx] = fmin(led_component_max, (float)intensity * ( sin( (float)refresh_cntr / led_chan_periods[chan_idx]) + 1));
			}

			// Update transient component of LEDs based on previous value and decay rate
			for (uint8_t idx = 0; idx < NUM_LEDS; idx++){
				const float decay_factor = 0.9;
				led_transient_component[idx] = decay_factor * led_transient_component[idx];
			}
//
//			// Define constant that compares how many refresh cycles need to occur before
//			// transient pulse "moves" to the next LED.
//			const uint8_t x_dot_over_refresh_rate = 1;
//
//			// If rollover occurred based on x_dot_over_refresh_rate
//			if (refresh_cntr % x_dot_over_refresh_rate == 0){
				// Set transient gain somewhere between 0 and 255
				transient_gain = (float)(4095 - adc_reads[ADC_RANK_TRANSIENT_GAIN]) * (127.0 / 4095.0);

				// Shift transient impulses by 1
				for (uint8_t led_idx = NUM_LEDS - 1; led_idx > 0; led_idx--){
					transient_locations[led_idx] = transient_locations[led_idx-1];
				}

				// If a transient has occurred since the last time we checked
				if (transient_present > 0){
					// Start transient on first LED
					transient_locations[0] = 1;
				} else{
					transient_locations[0] = 0;
				}

				// Reset Transient counter
				transient_present = 0;

				// In any location where a transient has just moved, set led_transient_component
				for (uint8_t led_idx = 0; led_idx < NUM_LEDS; led_idx++){
					if (transient_locations[led_idx] > 0){
//						led_transient_component[led_idx] = 1.0f;
						led_transient_component[led_idx] = transient_gain;
					}
				}
//			}

			// Cycle through each LED and each color channel
			uint32_t ccr_idx = 0;
			for(int16_t led_idx = 0; led_idx < NUM_LEDS; led_idx++){
				for(uint8_t chan_idx = 0; chan_idx < NUM_LED_CHANNELS; chan_idx++){
					// Calculate channel color for this LED by scaling and combining intensity and transient component
					i_and_t = led_intensity_component[chan_idx] + led_transient_component[led_idx];
					led_vals[led_idx][chan_idx] = (uint8_t)(fminf(i_and_t, 255.0));

					// Generate array for Timer CCR values corresponding to each bit that will be written to LEDs
					for(int8_t bit_idx = 7; bit_idx >=0; bit_idx--){
						if((led_vals[led_idx][chan_idx] & (0b1 << bit_idx)) > 0){
							ccr_sequence[ccr_idx] = ccr_one;
						}
						else{
							ccr_sequence[ccr_idx] = ccr_zero;
						}
						ccr_idx++;
					}
				}
			}

			// Set timer ARR for duration to write one bit to LEDs
			LL_TIM_SetAutoReload(TIM2, led_arr);

			// Clear any pending status registers
			CLEAR_REG(TIM2->SR);
			SET_BIT(DMA1->IFCR, DMA_IFCR_CGIF1 | DMA_IFCR_CGIF2);

			// Reset DMA counter
			LL_DMA_SetDataLength(DMA1, LL_DMA_CHANNEL_2, NUM_CCRS);

			// Enable DMA
			LL_DMA_EnableChannel(DMA1, LL_DMA_CHANNEL_2);

			// Enable DMA requests triggering on timer update events
			LL_TIM_EnableDMAReq_UPDATE(TIM2);

			// Enable counter. State will transition on the next update event
			LL_TIM_EnableCounter(TIM2);
			break;
		case TIM_UE:
			// Transition to next state
			transition(led_s);
		default:
			break;
    }
}

void led_s(Event evt){
    switch(evt){
		case ENTER:
			// By this point, sampling the ADCs and running DSP is assumed to have kept
			// output low long enough for reset pulse. No need to wait for it explicitly.
			break;
		case LED_DMA_COMPLETE:
			// By this point, all LEDs have been written to.
			// Transition state
			transition(config_mic_s);
			break;
		default:
			break;
    }
}

/* USER CODE END 0 */

/**
  * @brief  The application entry point.
  * @retval int
  */
int main(void)
{

  /* MCU Configuration--------------------------------------------------------*/

  /* Reset of all peripherals, Initializes the Flash interface and the Systick. */
  LL_APB2_GRP1_EnableClock(LL_APB2_GRP1_PERIPH_SYSCFG);
  LL_APB1_GRP1_EnableClock(LL_APB1_GRP1_PERIPH_PWR);

  /* System interrupt init*/
  NVIC_SetPriorityGrouping(NVIC_PRIORITYGROUP_0);

  /* Configure the system clock */
  SystemClock_Config();

  /* Initialize all configured peripherals */
  MX_GPIO_Init();
  MX_DMA_Init();
  MX_TIM2_Init();
  MX_ADC1_Init();
  /* USER CODE BEGIN 2 */
	// Calculate LCM for LED periods
	led_chan_periods_lcm = (uint32_t)led_chan_periods[0];
	for (uint8_t chan_idx = 1; chan_idx < NUM_LED_CHANNELS; chan_idx++){
		led_chan_periods_lcm *= (uint32_t)led_chan_periods[chan_idx];
	}

  	// Peripheral Configuration ~~~~~~~~~~~~~~~~~~~~~~~~~~~~~~~~~~~~~~~~~~~~~~~~~
	// Configure DMA for transfer from ADC to memory
  LL_DMA_DisableChannel(DMA1, LL_DMA_CHANNEL_1);
  LL_DMA_SetPeriphAddress(DMA1, LL_DMA_CHANNEL_1, (uint32_t)&ADC1->DR);
  LL_DMA_SetMemoryAddress(DMA1, LL_DMA_CHANNEL_1, (uint32_t)adc_reads);
	LL_DMA_EnableIT_TC(DMA1, LL_DMA_CHANNEL_1); // Enable interrupt to be called when transaction complete


	// Configure DMA for transfer from memory to Timer CCR
	LL_DMA_SetPeriphAddress(DMA1, LL_DMA_CHANNEL_2, (uint32_t)&TIM2->CCR1);
	LL_DMA_SetMemoryAddress(DMA1, LL_DMA_CHANNEL_2, (uint32_t)ccr_sequence);
	LL_DMA_EnableIT_TC(DMA1, LL_DMA_CHANNEL_2); // Enable interrupt to be called when transaction complete

	// Calibrate ADC for better accuracy
    LL_ADC_StartCalibration(ADC1, LL_ADC_SINGLE_ENDED);
    while(LL_ADC_IsCalibrationOnGoing(ADC1)){
  	  LL_mDelay(100);
    }

    // Enable ADC (but don't start)
    LL_ADC_Enable(ADC1);
	LL_ADC_EnableIT_OVR(ADC1); // Enable Overrun interrupt

	// Configure TIM
	CLEAR_REG(TIM2->SR);
	LL_TIM_EnableIT_UPDATE(TIM2); // Enable update event interrupt
	LL_TIM_CC_EnableChannel(TIM2, LL_TIM_CHANNEL_CH1); // Enable Capture compare channel
	LL_TIM_CC_SetDMAReqTrigger(TIM2, LL_TIM_CCDMAREQUEST_UPDATE); // Set DMA Request source


	// Enter starting state ~~~~~~~~~~~~~~~~~~~~~~~~~~~~~~~~~~~~~~~~~~~~~~~~~~~~~~~
	transition(config_mic_s);

  /* USER CODE END 2 */

  /* Infinite loop */
  /* USER CODE BEGIN WHILE */
  while (1)
  {
    /* USER CODE END WHILE */

    /* USER CODE BEGIN 3 */
  }
  /* USER CODE END 3 */
}

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


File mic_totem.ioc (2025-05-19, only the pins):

Mcu.UserName=STM32F302R8Tx
PA0.Signal=ADC1_IN1
PA1.Signal=ADC1_IN2
PA13.GPIO_Label=TMS
PA13.Signal=SYS_JTMS-SWDIO
PA14.GPIO_Label=TCK
PA14.Signal=SYS_JTCK-SWCLK
PA4.Signal=ADC1_IN5
PA5.Signal=S_TIM2_CH1_ETR
PB3.GPIO_Label=SWO
PB3.Signal=SYS_JTDO-TRACESWO
PC0.Signal=ADCx_IN6
PC1.Signal=ADCx_IN7

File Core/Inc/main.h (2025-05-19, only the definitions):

#define TMS_Pin LL_GPIO_PIN_13
#define TMS_GPIO_Port GPIOA
#define TCK_Pin LL_GPIO_PIN_14
#define TCK_GPIO_Port GPIOA
#define SWO_Pin LL_GPIO_PIN_3
#define SWO_GPIO_Port GPIOB
#define NVIC_PRIORITYGROUP_0         ((uint32_t)0x00000007) /*!< 0 bit  for pre-emption priority,
#define NVIC_PRIORITYGROUP_1         ((uint32_t)0x00000006) /*!< 1 bit  for pre-emption priority,
#define NVIC_PRIORITYGROUP_2         ((uint32_t)0x00000005) /*!< 2 bits for pre-emption priority,
#define NVIC_PRIORITYGROUP_3         ((uint32_t)0x00000004) /*!< 3 bits for pre-emption priority,
#define NVIC_PRIORITYGROUP_4         ((uint32_t)0x00000003) /*!< 4 bits for pre-emption priority,

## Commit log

2024-09-03 redo filtering stages based on arch diagram. untested but builds
2024-09-04 make mre headway on signal processing. filters appear to be working
2024-09-10 polling from 5 ADC channels using DMA
2024-09-28 building with no errors or warnings, untested
    [main.c]
2024-09-30 debugging with LL, checked TIM2 and ADC1 interrupts which may now be called successfully, but still need to resolve DMA interrupt not being called
    [main.c, main.h, mic_totem.ioc]
2024-10-02 fixed DMA issue, ADC inputs tested working
    [main.c, main.h]
2024-10-04 updated calcs document as starting to look at LED implementation
2024-10-04 prep for state machine: change to only one ADC read and DMA transfer while processing, add overrun flag
2024-10-08 transition to state machine architecture, placeholder for writing to LEDs but not yet implemented
2024-10-11 more state development, DMA not triggered for LEDs - need to debug
2024-10-16 finally figured out DMA on update event issue. Now need to determine why ccr_sequence is getting wiped out when timer started
    [main.c, mic_totem.ioc]
2024-10-17 fixed memory-peripheral reversal issue for DMA. Did some timing studies: Hopping between state machine functions appears to be the main delay when stopping LEDs, but no DMA errors thrown. Remaining t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
    [main.c, mic_totem.ioc]
2024-10-20 minor updates. came across bug where if I remove debugging variable 'led_config_cnt' then only go through state cycle once. checking in before larger changes for debug
    [main.c]
2024-10-20 issue resolved by force resetting counter using UG, also set DMA to regular mode (the right way) to de-risk spill-over when turning off LED timer. Timing calculations generally match measurements on 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
    [main.c, mic_totem.ioc]
2024-10-22 debugging. working through pesky issue where either ADC or DMA shift 0 index. Seems to be fixed with some while loops added, but sometimes just adding a line in config state is enough so not determin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
    [main.c, mic_totem.ioc]
2024-10-24 dialing in intensity component, added some DMA reset lines as well to de-risk errors from stop/starting
    [main.c]
2024-10-26 transient and intensity working well enough - shifting focus to EE design
    [mic_totem Debug.cfg]
2024-10-26 begin work on controller board schematic
    [mic_totem_ee-1_Main.SchDoc, mic_totem_ee.PcbLib, mic_totem_ee.PrjPcb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]
2024-10-28 more detail to schematic around MCU
    [mic_totem_ee-1_Main.SchDoc]
2024-10-30 update target FW and align to project, added debug connector after testing SWD interface, control schematic validated with no errors
    [mic_totem Debug.cfg, mic_totem_ee-1_Main.SchDoc, mic_totem_ee.PrjPcb]
2024-10-31 begin work on layout
    [mic_totem_ee-1_Main.SchDoc, mic_totem_ee.PcbDoc, mic_totem_ee.PrjPcb]
2024-11-04 Layout complete. Passing DRC. BomDoc Generated.
    [mic_totem_ee-1_Main.SchDoc, mic_totem_ee.PcbDoc, mic_totem_ee.PrjPcb]
2024-11-20 added note about fixing layout to schematic
    [mic_totem_ee-1_Main.SchDoc]
2025-01-08 transient detection generally working on custom PCBA. snapshot before revamping DSP to get faster and better filtering
    [mic_totem Debug.cfg, mic_totem_ee-1_Main.SchDoc, mic_totem_ee.PrjPcb]
2025-01-11 changed to integer filters. somewhat working
2025-01-11 found bug causing large processing delays so now can sample at roughly 80kHz. Now it appears the issue is more related to too small an input signal
    [main.c]
2025-01-12 updates for v3.1 complete
    [mic_totem_ee-1_Main.SchDoc, mic_totem_ee.PcbDoc, mic_totem_ee.PrjPcb]
2025-01-13 Begin work on LED Board
    [Bottom.SchDoc, Top.SchDoc, led_board_ee.PrjPcb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]
2025-01-15 first pass component placement for LED board top side
    [Bottom.SchDoc, Top.SchDoc, led_board_ee.PcbDoc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]
2025-01-19 v3.1 release of control board, v1.0 of LED board
    [led_board_ee.PcbDoc, led_board_ee.PrjPcb]
2025-02-15 isolated instensity signal to get it working, changed intensity to downsampled env to simplify
    [mic_totem_ee-1_Main.SchDoc]
2025-05-12 publish schematic info, minor updates on code (ongoing, untested)
    [mic_totem_ee-1_Main.SchDoc, mic_totem_ee.PrjPcb]

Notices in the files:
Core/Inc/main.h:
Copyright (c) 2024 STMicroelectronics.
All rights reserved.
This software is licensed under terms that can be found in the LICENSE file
